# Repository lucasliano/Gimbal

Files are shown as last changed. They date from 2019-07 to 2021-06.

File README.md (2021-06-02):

<!-- Badged -->





<!-- PROJECT LOGO -->
<br />
<p align="center">
  <a href="https://github.com/lucasliano/Gimbal">
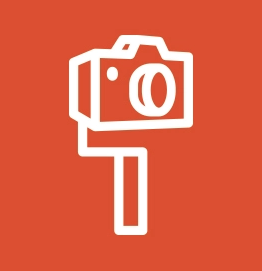
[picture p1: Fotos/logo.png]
    
  </a>

  <h3 align="center">3-Axis Gimbal</h3>

  <p align="center">
    Proyecto integrador de la materia Informática II, correspondiente a la carrera en Ing. Electrónica de la UTN.BA.
    En este proyecto se desarrolló un estabilizador de cámara GoPro de tres ejes.
    <br />
    <a href="https://github.com/lucasliano/Gimbal/blob/master/EntregaFinal/Gimbal%20Informe.pdf"><strong>Explore the docs »</strong></a>
    <br />
    <br />
    <a href="https://github.com/lucasliano/Gimbal/blob/master/Fotos">View Demo</a>
    ·
    <a href="https://github.com/lucasliano/Gimbal/issues">Report Bug</a>
    ·
    <a href="https://github.com/lucasliano/Gimbal/issues">Request Feature</a>
  </p>
</p>

<!-- ABOUT THE PROJECT -->
## About The Project




La idea fuerza del proyecto surgió gracias a las nuevas tecnologías utilizadas para la
transmisión de espectáculos en grandes espacios abiertos, tales como recitales o encuentros
deportivos en grandes estadios. El método utilizado inicialmente se basó en la utilización de cables
tensados y rieles en los cuales mediante un soporte, los elementos de filmación serían comandados
remotamente. Sin embargo, lejos de ser una solución, formuló un problema aún mayor; a una
determinada altura, los factores climáticos suponen un factor crítico a tener en cuenta que modifica la
precisión con la cual se puede manipular la herramienta de filmación.
Este inconveniente fue lo que motivó nuevos avances en materia de transmisiones. Referido
al problema inicial se propuso soportes acoplados en los extremos de las cámaras para poder
solventar el problema del viento y condiciones climáticas adversas.
A su vez, esta corriente tecnológica impulsó avances en la transmisión de deportes extremos
e individuales, para poder capturar experiencias que hasta el momento no podían ser alcanzadas. A
pesar de que no se trataba de deportes en los cuales la altura fuese un factor primordial, la velocidad,
los cambios bruscos de movimientos y repentinos presentaban el mismo problema descrito para
eventos masivos. La solución, sin embargo, esta vez fue diferente. Mediante la conjunción de
elementos que se detallarán a lo largo del documento, tanto en software y hardware, se logró el
elemento que nuestro proyecto intentará replicar, un estabilizador de cámara de tres ejes mediante
motores y algoritmos de control. Utilizaremos las cámaras para los cuales fueron diseñados
específicamente este elemento en primer lugar, las cuales pertenecen a la empresa goPro. En la
actualidad es posible utilizarlas en diferentes cámaras siempre y cuando se tenga en consideración el
peso y el tamaño de la cámara.

### Images

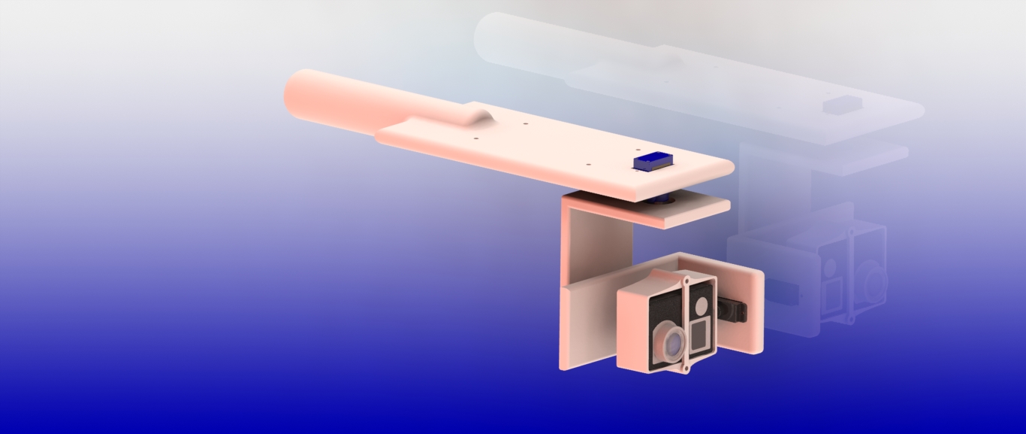
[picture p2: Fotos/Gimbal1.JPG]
gimbal


### Authors

* Coiro, Mateo
* Golob, Lautaro
* [Liaño, Lucas](https://github.com/lucasliano)
* [Lovallo, Alejo](https://github.com/AlejoLovallo)
* Repetto, Facundo

<!-- CONTRIBUTING -->
## Contributing

Contributions are what make the open source community such an amazing place to be learn, inspire, and create. Any contributions you make are **greatly appreciated**.

1. Fork the Project
2. Create your Feature Branch (`git checkout -b feature/AmazingFeature`)
3. Commit your Changes (`git commit -m 'Add some AmazingFeature'`)
4. Push to the Branch (`git push origin feature/AmazingFeature`)
5. Open a Pull Request

<!-- LICENSE -->
## License

Distributed under the MIT License. See `LICENSE` for more information.

<!-- CONTACT -->
## Contact

Lucas Liaño - lliano@frba.utn.edu.ar

Project Link: [https://github.com/lucasliano/Gimbal](https://github.com/lucasliano/Gimbal)

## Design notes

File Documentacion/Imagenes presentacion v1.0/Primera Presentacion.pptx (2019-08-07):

## Organización del TPO

- Diseñar:
  - Modelo 3D
  - Modelo matemático y físico
  - Modelo máquinas de estado (como funciona y lógica de abstracción)
  - Capa de aplicación
  - Capa de enlace
  - Capa física
  - Interfaz gráfica

## ¿Qué es un Gimbal?

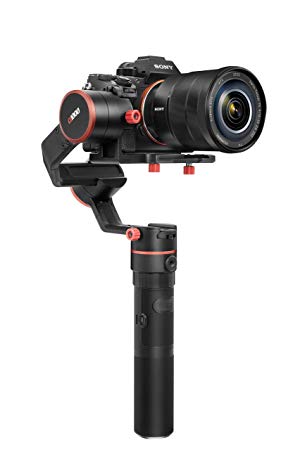
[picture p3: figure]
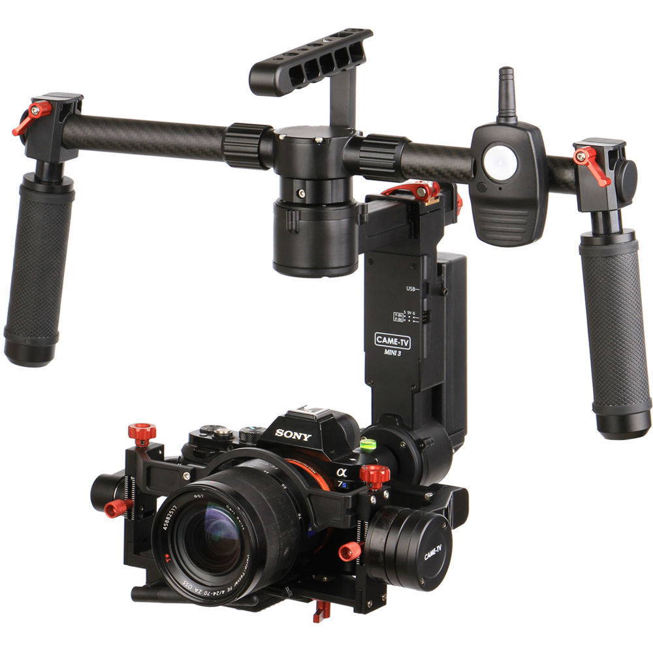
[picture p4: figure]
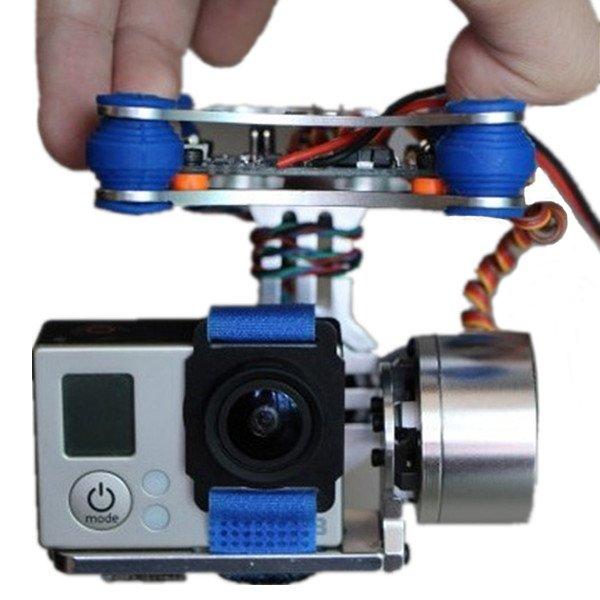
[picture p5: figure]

## Modelo 3D

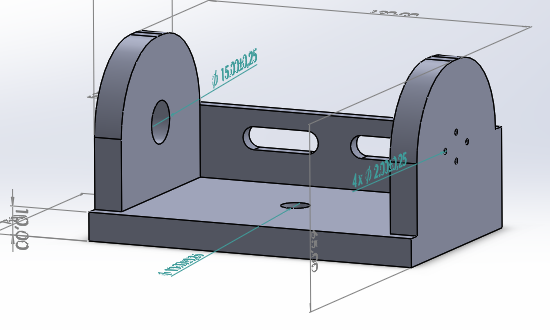
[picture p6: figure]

## Modelo 3D

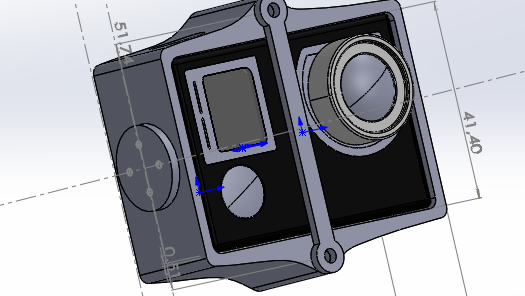
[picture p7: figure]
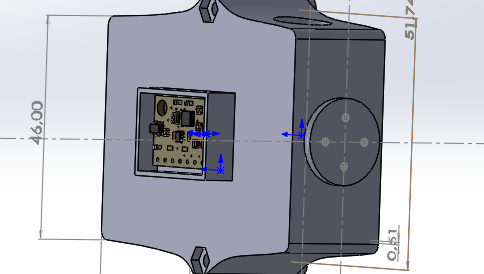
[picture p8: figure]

## Modelo Matemático y Físico

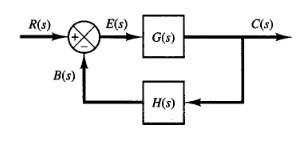
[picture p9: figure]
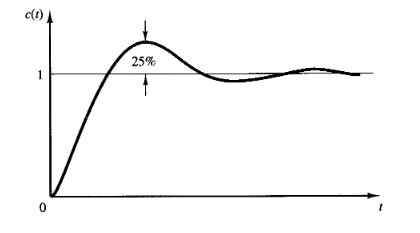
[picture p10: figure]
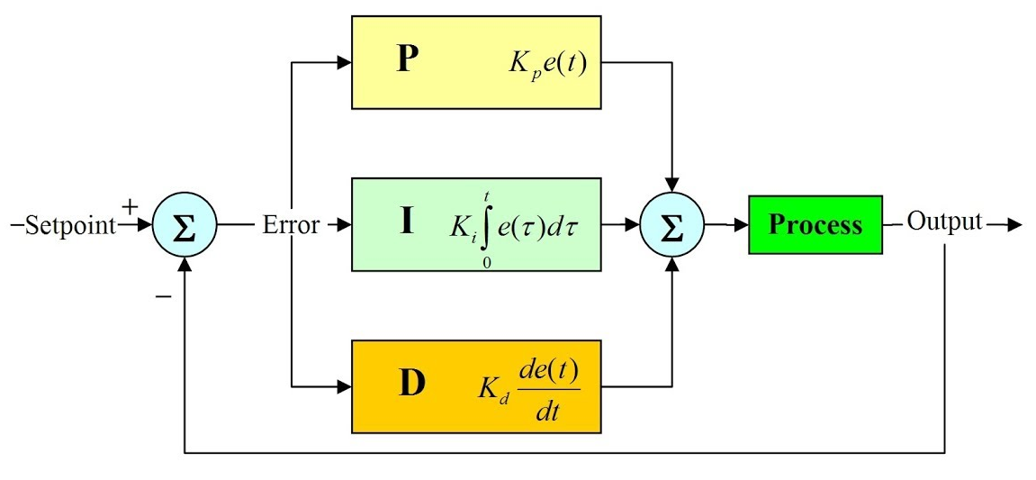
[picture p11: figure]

## Lógica de abstracción

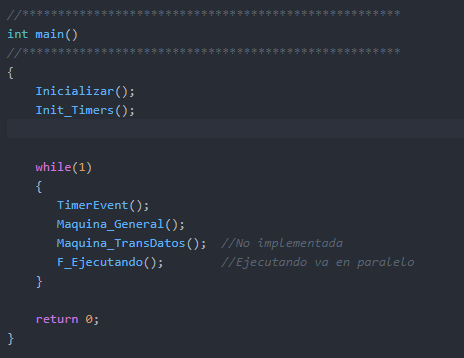
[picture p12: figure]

## Lógica de abstracción

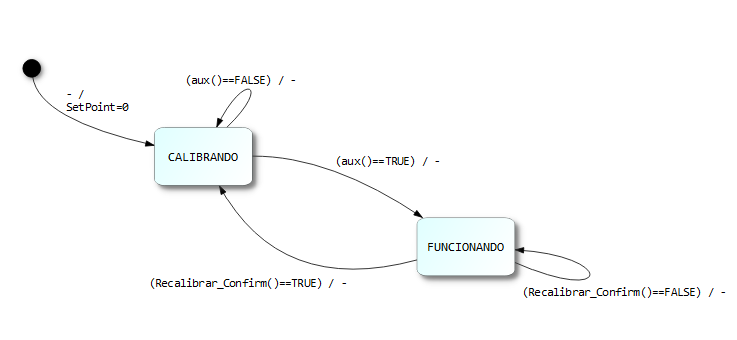
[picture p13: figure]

Maquina_General

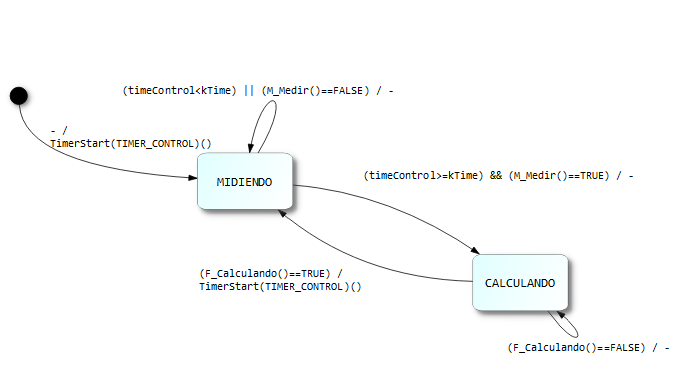
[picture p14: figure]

## Lógica de abstracción

Maquina_Control

## Capa de aplicación

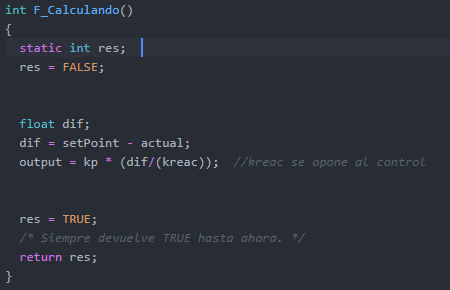
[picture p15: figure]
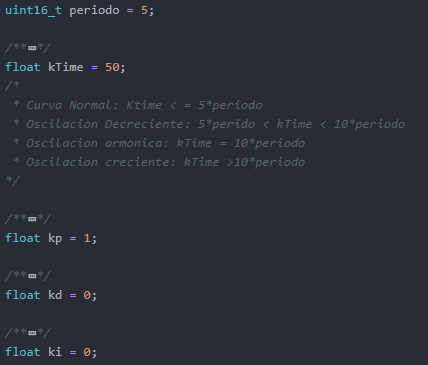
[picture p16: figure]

## Capa de “primitivas”

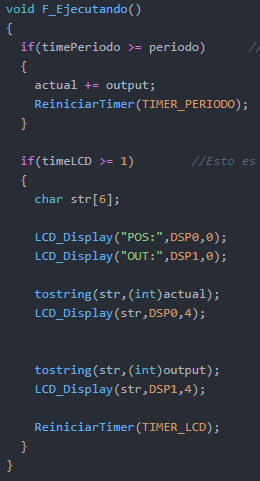
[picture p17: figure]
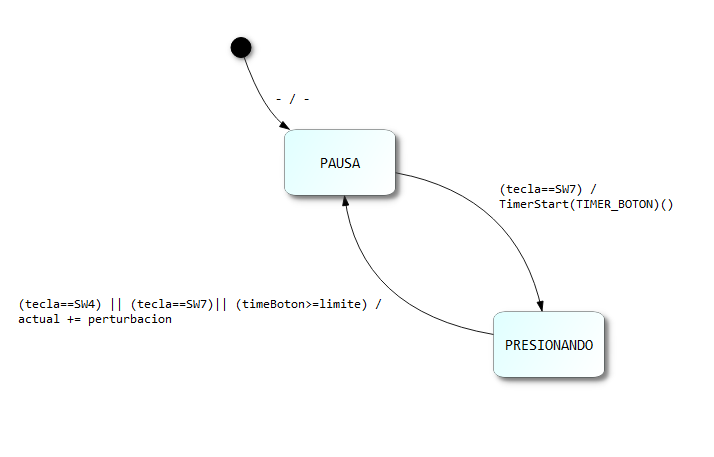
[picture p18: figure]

## Interfaz gráfica

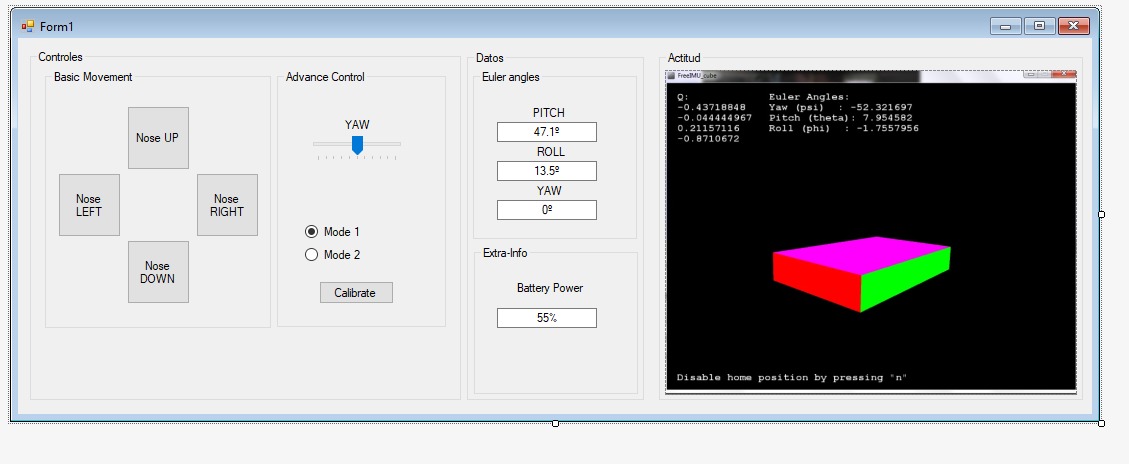
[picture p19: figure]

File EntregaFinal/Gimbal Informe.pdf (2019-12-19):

Universidad Tecnológica Nacional | Facultad Regional Buenos Aires
Departamento de Electrónica | Informática II - Plan 95A

# Trabajo Práctico Obligatorio: Informe

Materia: Informática II - Ing. Electrónica - U.T.N-F.R.B.A.

Docente titular: Ing. Nahuel Gonzalez

Ayudante de primera: Ing. Lisandro Sugezky

Ayudantes de segunda: Nicolás Campos

Federico Bua

Jefe de cátedra: Ing. Marcelo Giura

Integrantes: | Coiro, Mateo

Golob, Lautaro

Liaño, Lucas

Lovallo, Alejo

Repetto, Facundo

Trabajo Práctico Obligatorio | 1

# Estabilizador de cámara Gimbal

El propósito de este documento es resumir de manera informativa y práctica los aspectos técnicos del proyecto integrador.

- Estabilizador de cámara Gimbal
- Objetivo
- Descripción
- Marco Teórico
- Actuadores:
- Control:
■ Funcionamiento:
- Filtros:
- Recursos Complementarios
- Impresión 3D
- Módulos externos
- Placa complementaria
- Materiales utilizados para las placas
- Problemas y Soluciones
- Máquinas de estados:
- Interfaz gráfica:
- I2C:
- Traspaso del código a C++:
- Sistema de Control:
- Filtros:

Conclusiones

## Objetivo

Realizar un proyecto integrador que capitalice los conocimientos aprendidos durante la materia de Ingeniería Electrónica de segundo año, Informática II.
Los integrantes del equipo de trabajo hemos decidido realizar un estabilizador de cámara de tres ejes, más conocido como Gimbal en la industria. Será desarrollado específicamente para una cámara GoPro Hero 4.

### Descripción

La idea fuerza del proyecto surgió gracias a las nuevas tecnologías utilizadas para la transmisión de espectáculos en grandes espacios abiertos, tales como recitales o encuentros deportivos en grandes estadios. El método utilizado inicialmente se basó en la utilización de cables tensados y rieles en los cuales mediante un soporte, los elementos de filmación serían comandados remotamente. Sin embargo, lejos de ser una solución, formuló un problema aún mayor; a una determinada altura, los factores climáticos suponen un factor crítico a tener en cuenta que modifica la precisión con la cual se puede manipular la herramienta de filmación.
Este inconveniente fue lo que motivó nuevos avances en materia de transmisiones. Referido al problema inicial se propuso soportes acoplados en los extremos de las cámaras para poder solventar el problema del viento y condiciones climáticas adversas.
A su vez, esta corriente tecnológica impulsó avances en la transmisión de deportes extremos e individuales, para poder capturar experiencias que hasta el momento no podían ser alcanzadas. A pesar de que no se trataba de deportes en los cuales la altura fuese un factor primordial, la velocidad, los cambios bruscos de movimientos y repentinos presentaban el mismo problema descrito para eventos masivos. La solución, sin embargo, esta vez fue diferente. Mediante la conjunción de elementos que se detallarán a lo largo del documento, tanto en software y hardware, se logró el elemento que nuestro proyecto intentará replicar, un estabilizador de cámara de tres ejes mediante motores y algoritmos de control. Utilizaremos las cámaras para los cuales fueron diseñados específicamente este elemento en primer lugar, las cuales pertenecen a la empresa goPro. En la actualidad es posible utilizarlas en diferentes cámaras siempre y cuando se tenga en consideración el peso y el tamaño de la cámara.

### Marco Teórico

Centraremos nuestro análisis en tres ejes fundamentales para la comprensión de los fundamentos y complejidades del proyecto: Actuadores, Control-Filtros:

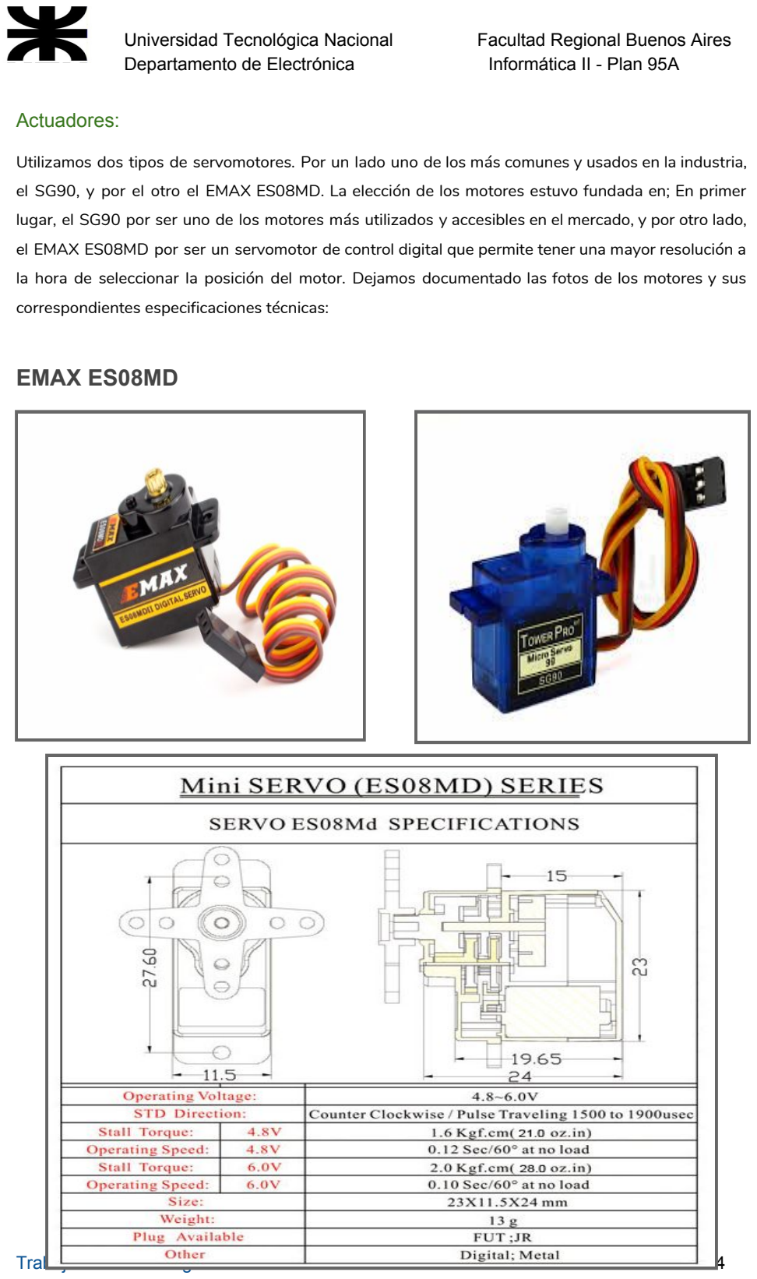
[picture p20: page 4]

Actuadores:

Utilizamos dos tipos de servomotores. Por un lado uno de los más comunes y usados en la industria, el SG90, y por el otro el EMAX ES08MD. La elección de los motores estuvo fundada en; En primer lugar, el SG90 por ser uno de los motores más utilizados y accesibles en el mercado, y por otro lado, el EMAX ES08MD por ser un servomotor de control digital que permite tener una mayor resolución a la hora de seleccionar la posición del motor. Dejamos documentado las fotos de los motores y sus correspondientes especificaciones técnicas:

### EMAX ES08MD

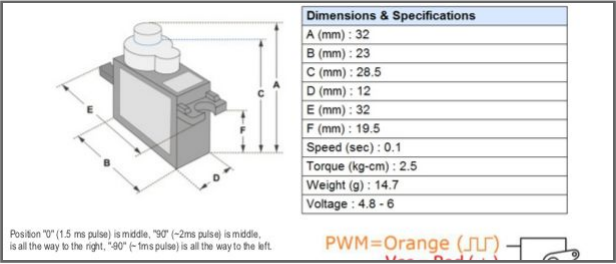
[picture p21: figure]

Control:

Se utilizó un mecanismo de control ampliamente conocido y utilizado en sistemas de control industrial por sus siglas: P.I.D (Controlador Proporcional, Integral y Derivativo). El mismo se basa de un sistema de realimentación, el cual calcula la desviación o error entre un valor medio y un valor deseado. El controlador puede proveer una acción de control adaptada a los requerimientos del proceso en específico. La respuesta del controlador puede describirse en términos de respuesta del control ante un error, el grado el cual el controlador sobrepasa el punto de ajuste, y el grado
de | oscilación | del sistema. Nótese que el uso del PID para control no garantiza un control óptimo
del sistema o la estabilidad del mismo.

Funcionamiento:

Para el correcto funcionamiento se necesita al menos:

- Sensor
- Controlador
- Actuador

A su vez, los tres componentes de un controlador PID son:

- Parte Proporcional --- constante proporcional.
- Acción Integral -------- tiempo Integral.
- Acción Derivativa ---- tiempo derivativo.

El sensor proporciona una señal analógica o digital al controlador, la cual representa el punto actual en el que se encuentra el proceso o sistema.
El controlador recibe una señal externa que representa el valor que se desea alcanzar, en nuestro caso el setPoint, el cual es de la misma naturaleza y tiene el mismo rango de valores que la señal que proporciona el sensor.

El controlador resta la señal de punto actual a la señal de punto de consigna, obteniendo así la señal de error, que determina en cada instante la diferencia que hay entre el valor deseado (consigna) y el valor medido. La señal de error es utilizada por cada uno de los tres componentes del controlador PID. Las tres
señales sumadas, componen la señal de
salida que el controlador va a utilizar para
gobernar al actuador. La señal resultante de la suma de estas tres se llama variable manipulada y no se aplica directamente sobre el actuador, sino que debe ser transformada para ser compatible con el
actuador utilizado.

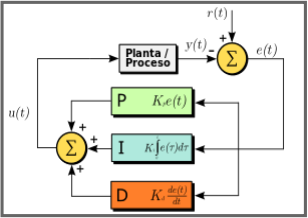
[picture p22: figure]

Se pretenderá lograr que el bucle de control corrija eficazmente, y, en el mínimo tiempo posible los efectos de las perturbaciones.

### Filtros:

Debido a la implementación de la I.M.U(Inertial measurement unit), es necesario aplicar filtros para la generación de ángulos de euler. En este caso en particular, utilizamos un filtro complementario que fusiona el ángulo generado a partir de la integración de la velocidad angular en un período AT junto con el ángulo generado a partir de cálculos trigonométricos sobre el vector gravedad, medido desde el acelerómetro. Por otro lado, aplicamos un filtro de media móvil exponencial aplicado como pasa-bajo. Esto se debe a que los datos tomados de la IMU tienen fluctuaciones de alta frecuencia.

### Proceso (https://es.wikipedia.org/wiki/N%C3%BAmeros_complejos)

El proceso para la organización y realización del proyecto fue diagramado por el cuerpo docente a cargo de la materia y posteriormente nuestro equipo lo modificó de acuerdo a las necesidades de nuestro proyecto en cuestión:

1. Presentación de la idea fuerza.
2. Establecimiento de limitaciones y alcance del proyecto coordinadas con el cuerpo docente:
- Desarrollo completo del modelo mecánico, tanto diseño como simulación e impresión del chasis del gimbal.

- Desarrollo del firmware que contará con funciones que posibiliten la rotación del soporte en torno a sus propios ejes y un modo de uso que permitirá controlar el sistema para mantener constante la actitud del soporte central de uno de los tres ejes.
- Desarrollo de una interfaz gráfica que pueda controlar y visualizar la actitud del dispositivo.
3. Lógica del proyecto mediante máquinas de estado.

Inicialmente se diagramó una lógica que contemplaba tres máquinas de estados

- Máquina general
- Máquina de control
- Máquina de transmisión de datos

Máquina General: La máquina general se encarga de las tareas principales que debe cumplir el sistema. La misma cuenta, a esta altura del proyecto, con dos estados FUNCIONANDO y CALIBRANDO. La máquina va a iniciar en el estado CALIBRANDO y va a ejecutar las rutinas pertinentes a la calibración. Una vez haya logrado calibrarse, función que actualmente no contempla fallos, genera una transición hacia FUNCIONANDO.

En el estado funcionando, el programa va a ejecutar la máquina de control. Luego va a generar una transición hacia calibrando si se cumplen los requisitos de Recalibrar_confirm() = aux. Esto va a suceder ya sea porque se solicita una recalibración vía comunicación Serie o porque se ha congelado el micro.

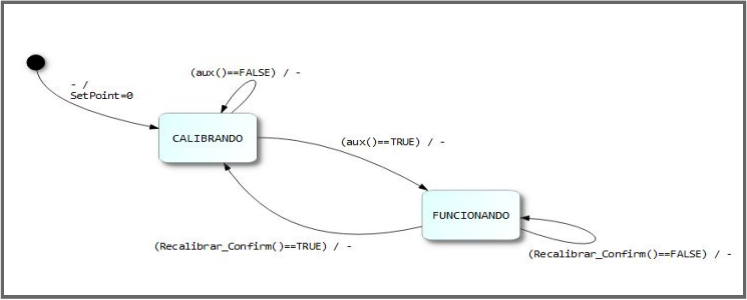
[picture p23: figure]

Máquina Control: La máquina de control se encarga de alternar entre mediciones y cálculo de datos. La transición es temporizada y depende de una constante de control kTime. Dentro del estado MIDIENDO se realizan cuantas mediciones sean posibles de datos y se procesan obteniendo ángulos de Euler. Cuando se genera la transición al estado CALCULANDO, se ejecutan los cálculos del sistema de control, obteniendo como resultado una salida “output” que debe incrementarse en la variable “actual” (correspondiente a la función F_Ejecutando().

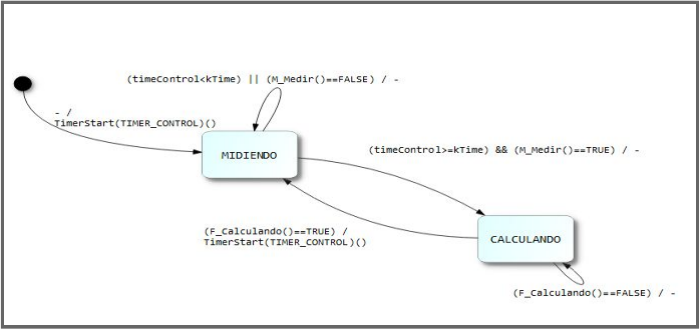
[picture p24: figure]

Máquina transferencia de datos: Esta máquina cuenta con 3 estados que se ocupan del correcto desempeño de la recepción de mensajes vía puerto serie. Estos tres estados son ESPERANDO_INICIO, ESPERANDO_TIPOS y RECIBIENDO_DATOS.

El estado inicial es ESPERANDO_INICIO. Allí se espera la llegada de un carácter ‘#’. Cuando eso ocurre, empieza la recepción de la trama y estado pasa a ser ESPERANDO_TIPO. En este nuevo estado se espera la llegada de 3 caracteres que definen el tipo de mensaje. Si la cantidad de caracteres que llegan hasta la llegada de un ‘@‘ es distinta a 3 unidades, entonces se descarta la trama y se vuelve al estado ESPERANDO_INICIO. Cuando la cantidad de caracteres recibidos supere 3 unidades sin la llegada de un ‘@‘, entonces el estado se modifica a RECIBIENDO_DATOS. Mientras la máquina se encuentre dentro de RECIBIENDO_DATOS, se esperará la llegada de un nuevo carácter y a continuación un ‘@‘. Si no se cumplen dichas condiciones, se descarta la trama. Si se cumplieran las condiciones, se llama a la la función AnalizarTrama(), quien verifica el tipo de dato y ejecuta acciones conforme al tipo de mensaje.

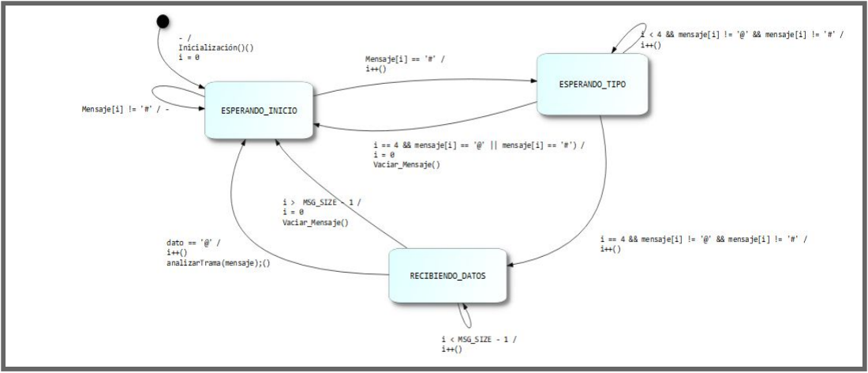
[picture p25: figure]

4. Modelizado del funcionamiento mediante la utilización de la librería de la cátedra conjuntamente con los periféricos incluidos en la placa.
5. Presentación de la interfaz gráfica del proyecto
6. Presentación de avances preliminares.
7. Presentación Final.

Se estableció una forma de trabajo en un principio conjunta y que posteriormente se dividiría por áreas para cumplir con los tiempos solicitados por la cátedra. A su vez, desde un primer momento incorporamos a nuestro modo de trabajo dos herramientas necesarias y sumamente útiles para cualquier tipo de proyecto;

- Documentación mediante Doxygen.
- Software de gestión de versiones de código, en nuestro caso mediante GitHub.

### Recursos Complementarios

### Impresión 3D

Era desde un primer momento, un aspecto a tener en cuenta desde que tomamos la decisión de avanzar en el proyecto. El estabilizador que se produce a nivel industrial utiliza materiales que eran perfectamente replicables a través de la impresión 3D. Por lo tanto, diseñamos cuatro piezas para que la cámara que utilizaremos, una GoPro Hero4 pueda ser utilizada en el proyecto.
Utilizamos el programa SolidWorks para el diseño en 3D de las piezas y para poder realizar el renderizado para que la impresora 3D comprenda el modelo realizado el software Cura.

Descripción de las piezas realizadas:

- Caja a medida para que colocar la cámara: el propósito de esta pieza es darle un alojamiento a la cámara.
- Tabique para sostener la cámara: por cuestiones de diseño, la realización de una tapa para que la cámara no se caiga era difícil de alcanzar por lo que se implementó un tabique en el el frente de la caja, a la cual se agujereó en el medio de la misma tanto en la

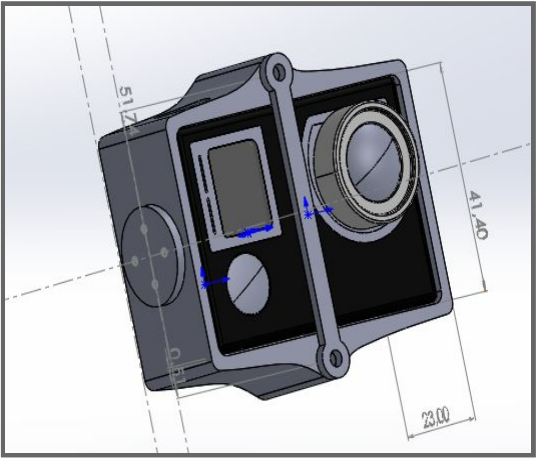
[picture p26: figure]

parte superior como inferior de la misma.

- Dos soportes los cuales forman ángulos perpendiculares entre sí y permiten que la sujeción de los servomotores para luego generar rotaciones.
- Mango para la manipulación del dispositivo y a su vez cumple la función de sujetar la placa a la base del mango.



### Módulos externos

Para realizar mediciones correspondientes recurrimos a uno de las unidades de medición inercial más conocidas como lo es el MPU-9250. El mismo es un integrado que cuenta con un giroscopio, un acelerómetro y un magnetómetro. También tiene interfáz para comunicación mediante tanto I2C com SPI.

Por otro lado, para generar una comunicación inalámbrica con Qt optamos por utilizar el módulo HC-06. Este es un módulo muy utilizado en el mundo Arduino capaz de comunicarse mediante Bluetooth con distintos dispositivos. Para conectarnos con él, solo tendremos que escribir en una UART, una vez hayamos configurado el módulo.

### Placa complementaria

Los motivos de la realización de una placa complementaria se encuentran en la necesidad de poder alimentar los servomotores de una manera práctica que permita el movimiento de los mismos, y la única manera de realizarlo era con el diseño y confección de una placa que pudiese estar montada sobre el gimbal, y como la placa provista por la cátedra no cumplía con nuestros requisitos decidimos realizar una nueva.


Materiales utilizados para las placas

- Dos Borneras de 2
- Un Diodo 1N5819
- Un Diodo 1N4007
- Dos Capacitores 0,1uF
- Dos Capacitores 0.22 uF

- Dos Capacitores 10mF x 16V
- Un Regulador LM7805
- Un Regulador LM1117T3.3
- Dos Resistencias 4,7Kohm
- Varias Tiras de pines hembra

### Problemas y Soluciones

### Máquinas de estados:

Al comienzo del año nuestro primordial objetivo fue consolidar cual iba a ser la lógica general del funcionamiento del dispositivo en cuestión. Para ello utilizamos como funciones de referencia, toda la biblioteca que proporciona la cátedra.
El principal problema que hubo con las máquinas de estado fue que en un primer momento se plantearon desde un nivel de aplicación bastante abstraído del funcionamiento de los drivers, sin considerar el comportamiento de las interrupciones. También tenemos en cuenta que para el comienzo del año no contábamos con los conocimientos acerca de las interrupciones.
La solución en este caso fue re-hacer parte del funcionamiento de las máquinas abstrayendo aún más la capa de aplicación, pero incluyendo más herramientas en la capa de primitivas.

### Interfaz gráfica:

Para el desarrollo de la interfaz gráfica se intentó desarrollar una aplicación que utilizara alguna librería gráfica como lo son Allegro o OpenGL. Nos encontramos con que estas librerías, en particular OpenGL, son bastante más complejas de lo que esperábamos. En ambos casos resultaba altamente dificultoso vincular las aplicaciones de Qt con las pantallas que generaban ambas herramientas. También se trató de agregar una aplicación externa, previamente realizada por uno de los integrantes, hecha en Java. Aquí el problema que encontramos era compatibilizar el método para acceder a la misma información, dado que no eran distintos procesos pero tampoco compartían las mismas variables globales. Qt no compatible con otros lenguajes ó entornos de trabajo.
En este caso, la solución que encontramos para representar gráficamente la actitud de la cámara fue la utilización de una librería propia de Qt (qcustomplot) para generar gráficos complejos en tiempo real. Aparte se agregó un feature para manipular las constantes de control desde la aplicación en la computadora.


I2C:

Referido al periférico I2C, podemos decir que fue una de nuestras mayores complicaciones, dado que nos costó entender que para poder solucionar los problemas que teníamos debíamos leer reiteradas veces el datasheet. Esto sumado a que para poder evaluar el comportamiento del periférico es necesario la utilización de instrumental como un osciloscopio, del cual no disponemos en nuestras casas, y también fue otro instrumento que debimos aprender a utilizar. Esta fue sin dudas, la etapa del proyecto más ardua y tediosa. Agradecemos el esfuerzo de los ayudantes para con nosotros y su paciencia y dedicación para poder sobrepasar esta etapa.

### Traspaso del código a C++:

Traspasar el firmware en MCU del lenguaje C al lenguaje C++ resultó ser más complicado de lo esperado. Para manipular la IMU, optamos con adquirir un código en c++ que contenía un objeto capaz de realizar muchas de las tareas necesarias. Si bien no terminamos utilizando la totalidad del objeto, dado que algunas de las rutinas contenían errores, de todas formas intentamos agregar este objeto en el firmware.
Para realizarlo, tuvimos que migrar el proyecto de C a C++. Esto implica que ahora es necesario que haya más de un compilador y un linker vinculados trabajando sobre el mismo código. Esto nos generó confusiones, dado que dependiendo cómo se declaran ciertos tipos de datos, defines o instrucciones pre-compilador, van a generar reacciones en algunas partes del código o no. Por tanto ciertos bugs que creíamos relacionados a la lógica del programa, terminaron estando vinculados con estos problemas de tener más de un compilador corriendo al mismo tiempo.

### Sistema de Control:

Diseñar e implementar un sistema de control no es nada trivial. A pesar de no tener conocimientos reales de control, intentamos implementar uno de los algoritmos más utilizados comercialmente como se mencionó anteriormente.
Nuestra ignorancia en esta área provocó que nos atrasemos demasiado en el desarrollo del proyecto. Resultó que nuestros actuadores (servomotores) resultan bastante difícil de modelar, o al menos así lo vemos nosotros, y generan interacciones no deseadas en el sistema.
Tuvimos para esta etapa la ayuda de uno de los grupos de investigación de la facultad, relacionado a drones, con lo cual han implementado varios sistemas de control distintos. Sin embargo, sólo fue una guía, completamente necesaria de todos modos, para poder realizarlo.

### Filtros:

Los filtros implementados fueron, en gran medida, diseñados por nosotros. Inicialmente, como se indicó en la sección de C++, se trató de utilizar un objeto diseñado por un profesional estadounidense. Este objeto utilizaba tanto las mediciones del acelerómetro, el giroscopio como del magnetómetro. Debido a que las mediciones obtenidas por el magnetómetro eran anormales, se buscó la forma de migrar el filtro. Por dicho motivo pasamos de utilizar el filtro Madgwic a utilizar un filtro complementario, junto con un filtro pasa-bajo, ambos diseñados por nosotros, o al menos en gran medida.
Los resultados obtenidos por los primeros intentos de filtros eran demasiado ruidosos (+/- 10 grados), por lo que no resultaban adecuados para nuestro dispositivo.
Luego de múltiples intentos, y una pequeña ayuda externa, logramos identificar dónde estaba el problema, en uno de los objetos al intentar realizar una pre-calibración. Por tomar como válido este cálculo externo, generamos datos erróneos los cuales generaban ruido en la señal de retroalimentación.
Una vez encontrado el problema, lo único que tuvimos que hacer fue re-hacer las funciones de calibración del objeto. Actualmente la señal resultante tiene un error de +/- 1 grado, lo cual tomamos como válido para nuestro fin.

### Conclusiones

A pesar de que el proyecto está orientado por la cátedra a que se evalúe solamente el software y no se contemple el hardware, el producto final al que se intentó llegar significó un desafío enorme para todo el equipo de trabajo. Tuvimos que lidiar con la inexperiencia de casi todos los integrantes en cuanto a hardware, diseño, armado y soldado de placas, protocolos de comunicación entre periféricos como lo fue I2C y sistemas de control. Con lo cual el tiempo empleado en tan sólo la comprensión de esos conocimientos fue muy grande comparado con el tiempo empleado en aplicarlos.

Sin embargo, al tratarse de una temática libre, la dificultad del proyecto fue alta desde un principio y a nuestro criterio, quizás no proyectamos los posibles inconvenientes y zonas de conflicto que podrían llegar a suceder mientras escalaba el proyecto. Fue desde un primer momento, una propuesta ambiciosa.

Si nos limitamos a evaluar de manera general si cumplimos con el objetivo inicial propuesto, podemos aseverar que se han alcanzado las condiciones mínimas del proyecto. Si lo detallamos, entonces la conclusión es que no estamos completamente satisfechos con los resultados. Es posible la realización de mejoras, tales como:

- Componentes, ya que los utilizados no son los más adecuados para el proyecto en cuestión.
- Filtros, ya que es la primera vez que realizamos este tipo de sistema.
- Control, por el mismo motivo detallado en filtros, consideramos que en esta área es dónde más mejoras podrían realizarse.

A pesar de todos los inconvenientes previamente mencionados a lo largo del documento, consideramos que la experiencia es en definitiva beneficiosa para el alumnado sobre todo en un ítem no mencionado, el trabajo en equipo. Destacamos el compromiso, organización y dedicación por parte de todos para con el proyecto y el entusiasmo y decisión con la que se llevó adelante todo el proceso desde el momento en que se decidió una idea y cuál era el camino a seguir.

Ciclo Lectivo 2019 | Curso Nº | R2003 | Grupo Nº | 3

## Integrantes

Apellido y nombres | Legajo | Califación individual | Fecha
Coiro, Mateo | 1672538 | | 16/12/2019
Golob, Lautaro | 1672587 | | 16/12/2019
Liaño, Lucas | 1674389 | | 16/12/2019
Lovallo, Alejo | 1673658 | | 16/12/2019
Repetto, Facundo | 1674705 | | 16/12/2019
Calificación Grupal: | Fecha: 16/12/2019
Profesor: | Ing. Nahuel Gonzalez
Auxiliar/es docente: | Ing. Lisandro Sugezky Sr. Nicolás Campos Sr. Federico Bua

### Observaciones primera entrega:

### Observaciones segunda entrega:

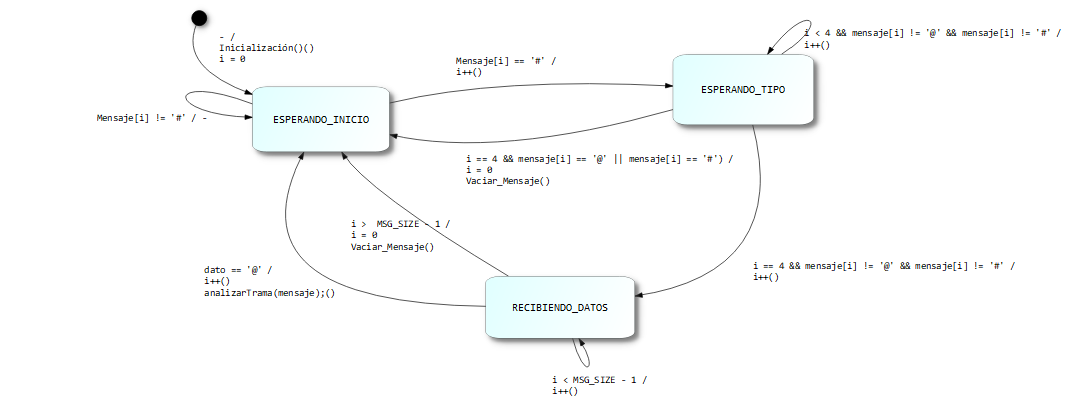
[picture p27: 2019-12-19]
Fotos/Maquina_TransDatos.png

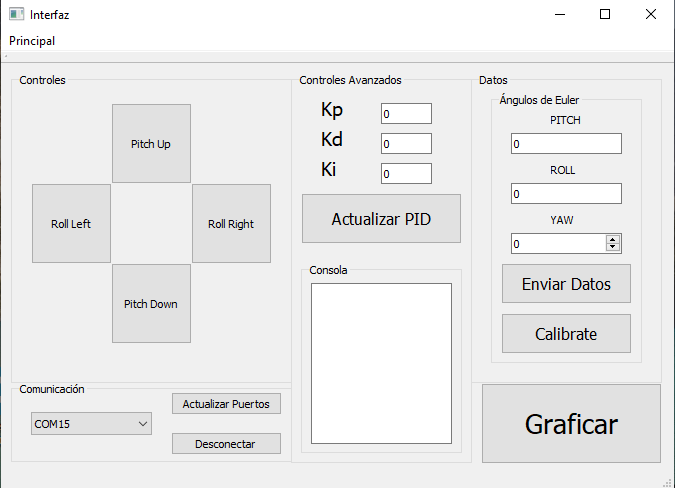
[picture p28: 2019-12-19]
Fotos/GUI-Activado.png

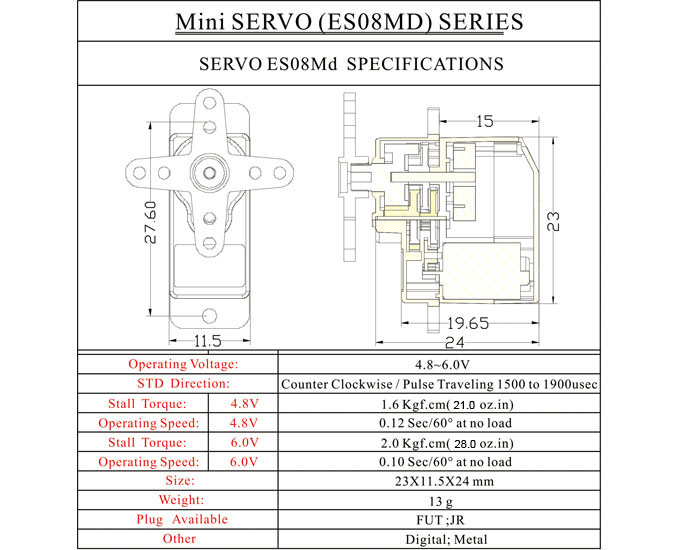
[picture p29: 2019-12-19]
EntregaFinal/FotosGimbal/EMX-SV-0276-DES-1.jpg

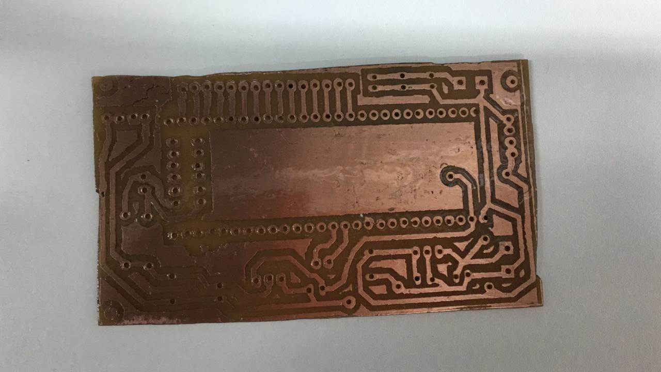
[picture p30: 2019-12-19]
EntregaFinal/FotosGimbal/PlacaComplementaria.jpg

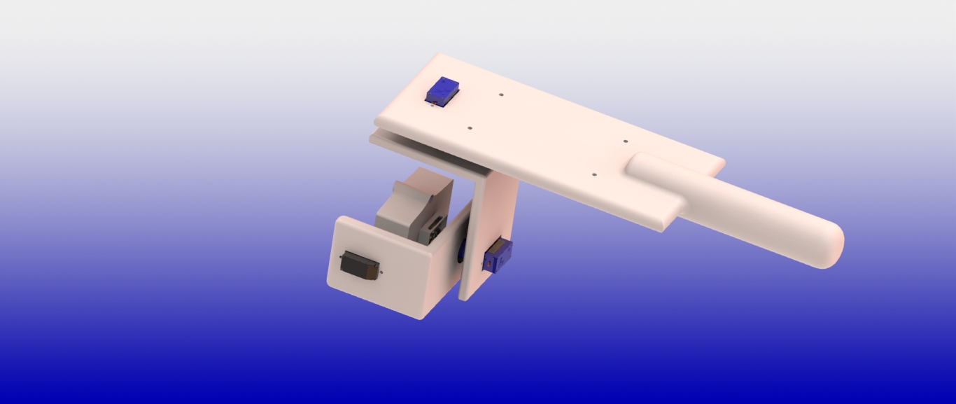
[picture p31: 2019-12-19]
Fotos/Gimbal3.JPG

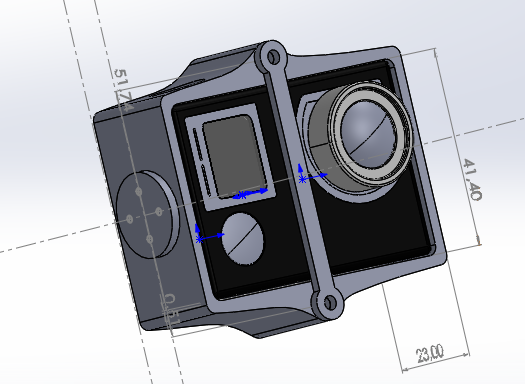
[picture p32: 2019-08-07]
EntregaFinal/FotosGimbal/Gimbal frente.png

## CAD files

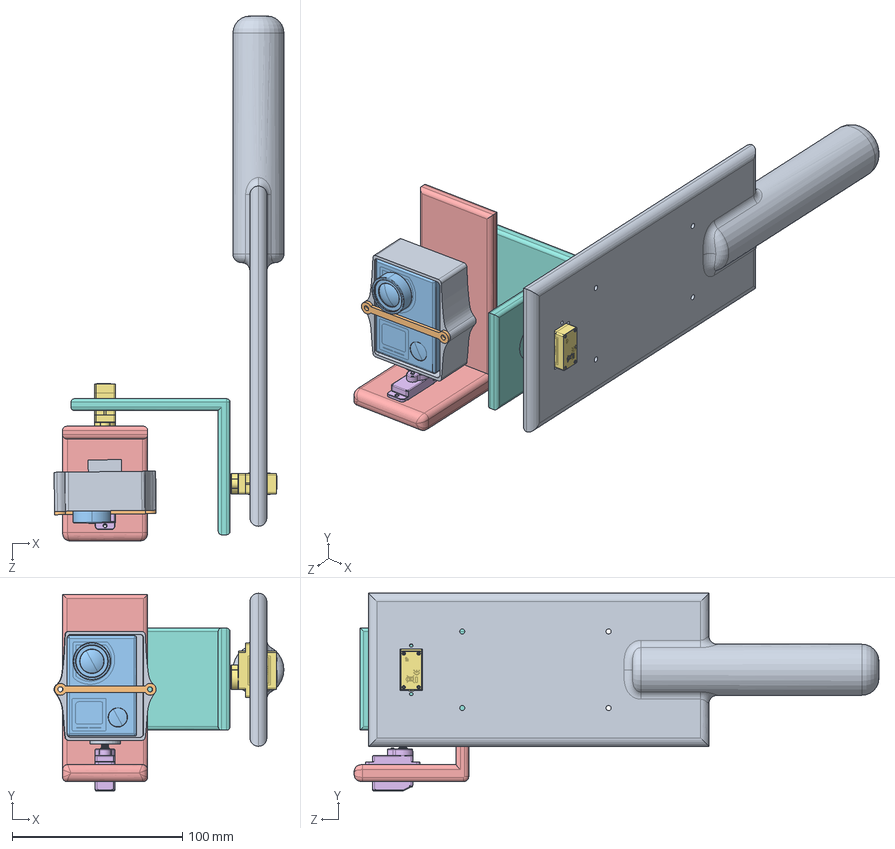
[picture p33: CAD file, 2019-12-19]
Piezas 3D/v3.0/Ensamblaje.SLDASM
135.2 x 116.2 x 308.6 mm
Pieza 1
Freno
Gopro Hero 4
GY-91
Pieza2
Emax ES08A
SG90 - Micro Servo 9g - Tower Pro.1 x 2
Pieza3
Pieza4

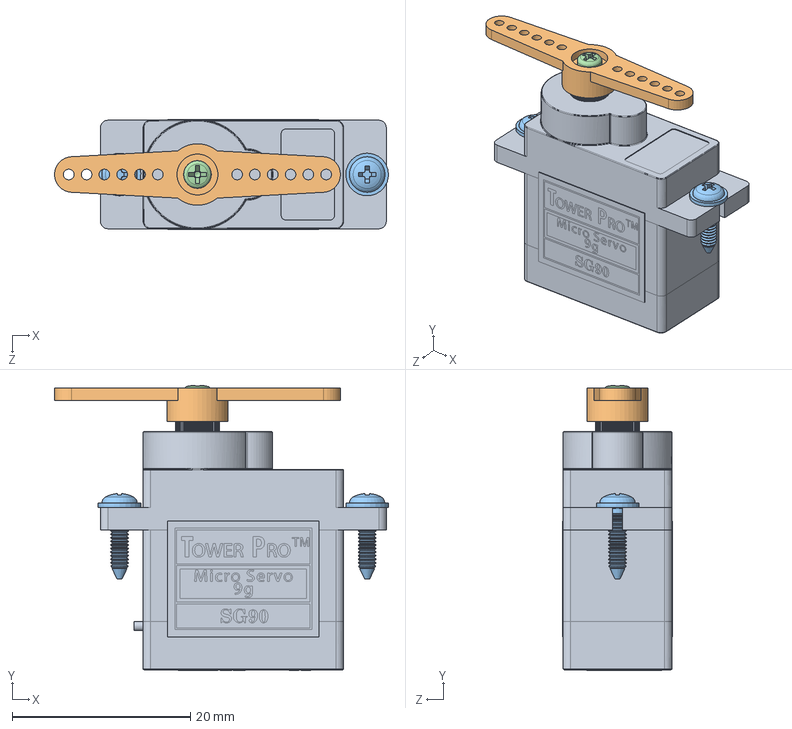
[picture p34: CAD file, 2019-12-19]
Piezas 3D/v3.0/Piezas externas/Servos/SG90/SG90 - Micro Servo 9g - Tower Pro.SLDASM
37.5 x 32.0 x 12.4 mm
SG90 - Micro Servo 9g - Tower Pro.1
SG90 - Micro Servo 9g - Tower Pro.3
SG90 - Micro Servo 9g - Tower Pro.5 x 2
SG90 - Micro Servo 9g - Tower Pro.6

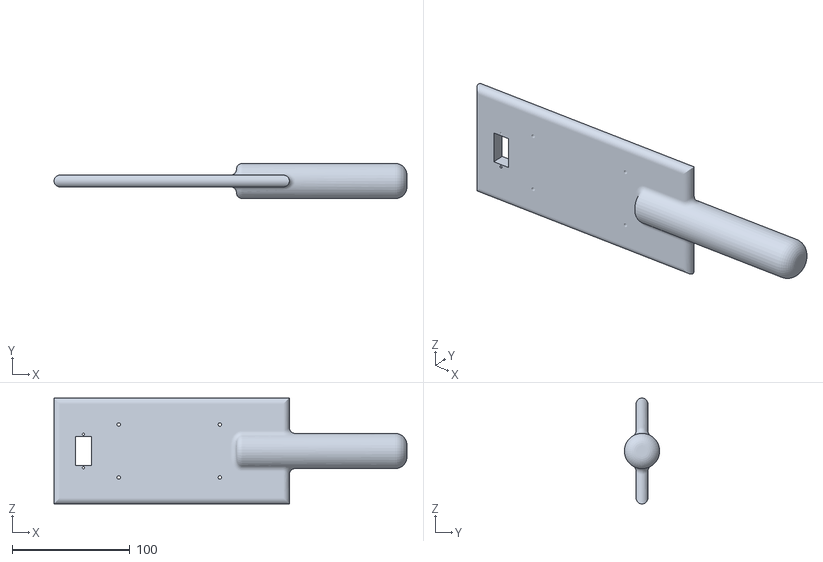
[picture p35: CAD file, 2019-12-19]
Piezas 3D/Pieza4.STL
300.0 x 30.0 x 90.0

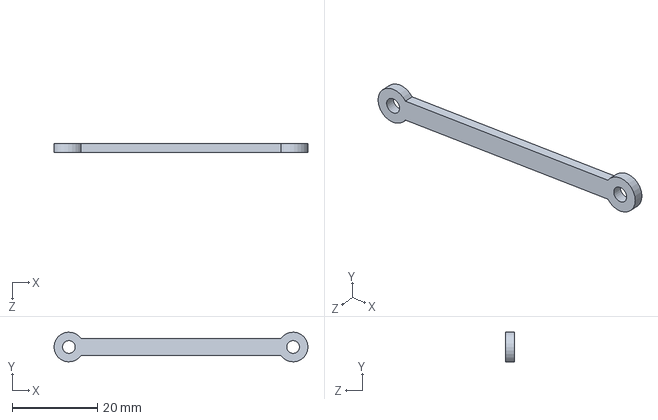
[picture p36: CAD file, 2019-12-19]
Piezas 3D/v3.0/Freno.SLDPRT
59.7 x 6.99 x 2.00 mm

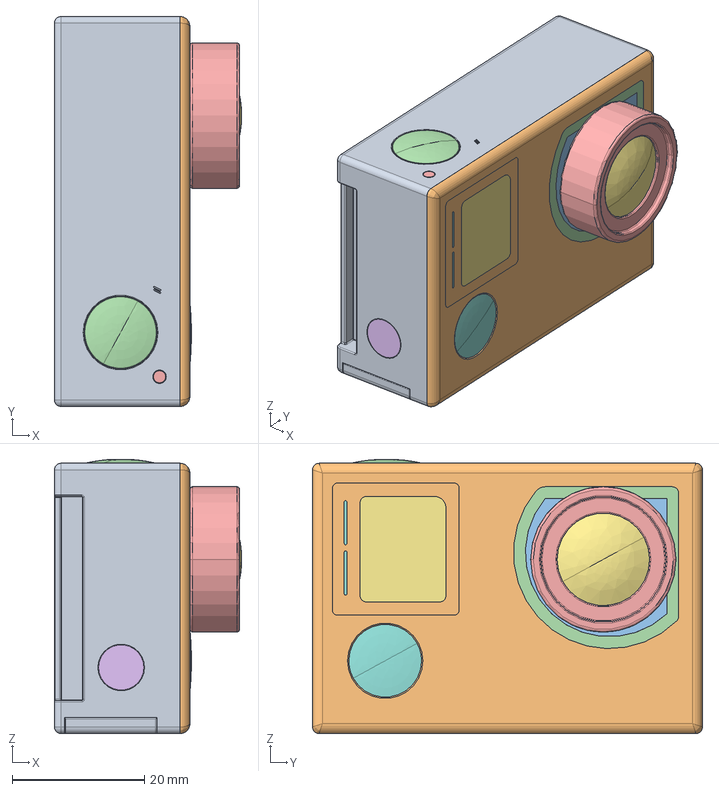
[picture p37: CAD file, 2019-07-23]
Piezas 3D/v3.0/Piezas externas/GoPro/Gopro Hero 4.stp
28.3 x 59.0 x 41.5 mm

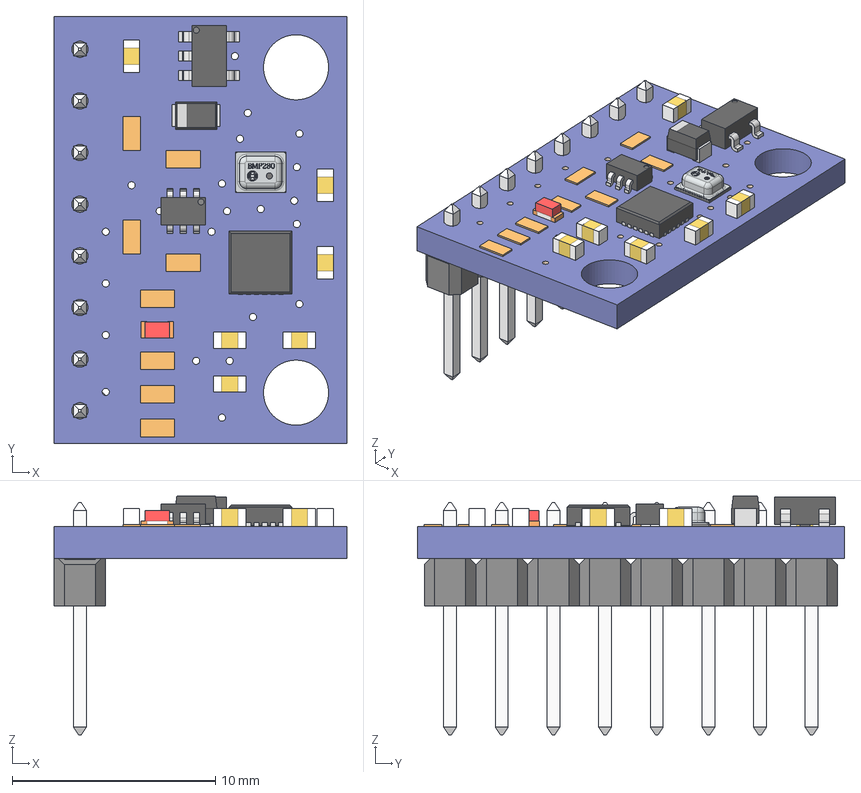
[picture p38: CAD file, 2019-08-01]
Piezas 3D/v3.0/Piezas externas/Gyro/GY-91.step
14.4 x 21.0 x 11.8 mm
Board
0.1µF x 6
BSS138PS(SOT-363)
Green
10µF
MIC550X-3v3
4.7kΩ x 8
2.54MM1X8
MPU9250
BMP280AU

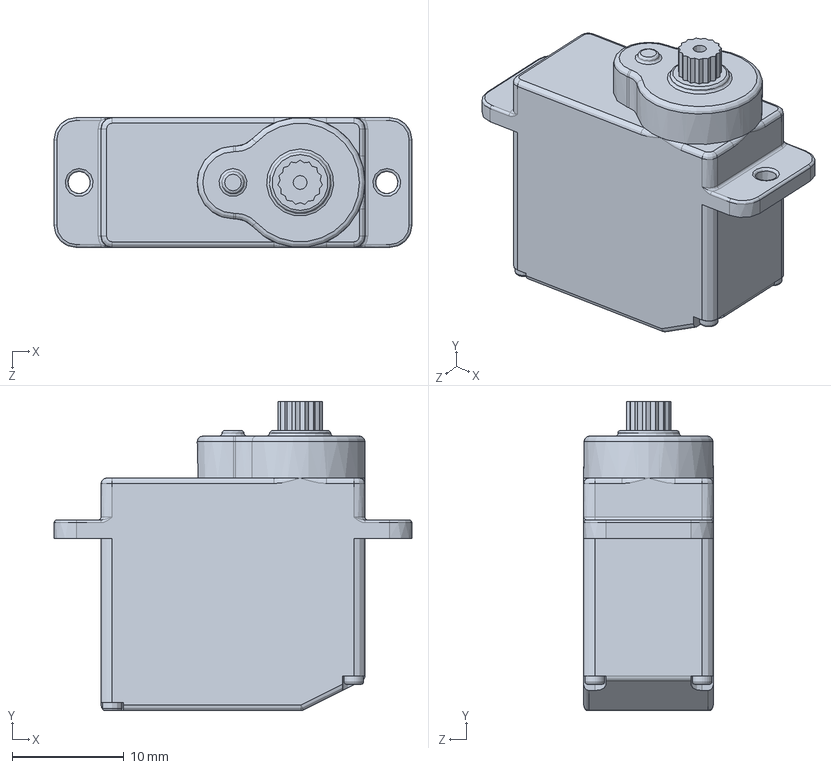
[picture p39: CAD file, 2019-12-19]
Piezas 3D/v3.0/Piezas externas/Servos/Emax - ES08A/Emax ES08A.SLDPRT
32.0 x 27.6 x 11.6 mm

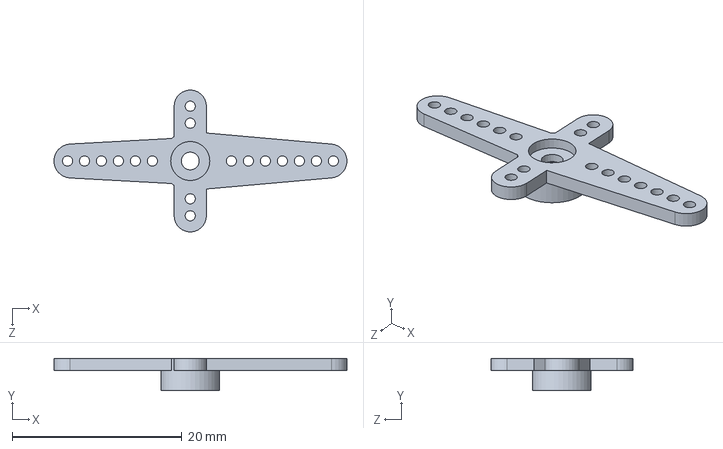
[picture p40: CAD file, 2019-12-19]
Piezas 3D/v3.0/Piezas externas/Servos/SG90/SG90 - Micro Servo 9g - Tower Pro.4.SLDPRT
34.5 x 3.80 x 16.7 mm

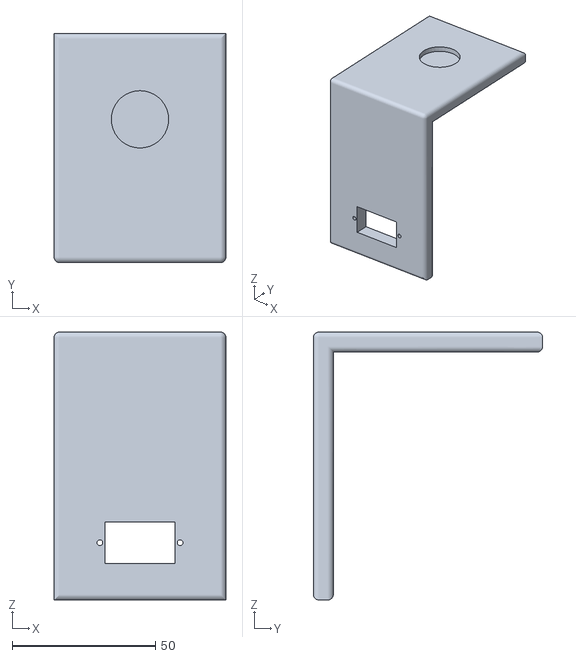
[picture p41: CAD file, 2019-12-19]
Piezas 3D/3era pieza.STL
60.0 x 80.0 x 93.5

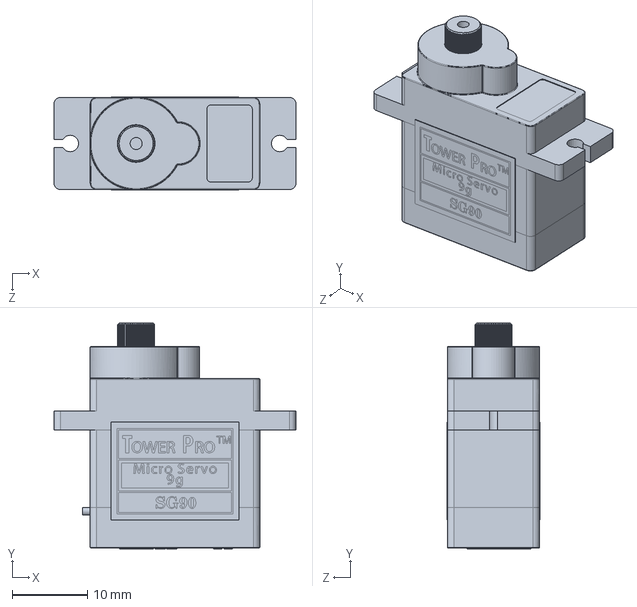
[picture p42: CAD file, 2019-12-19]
Piezas 3D/v3.0/Piezas externas/Servos/SG90/SG90 - Micro Servo 9g - Tower Pro.1.SLDPRT
32.1 x 30.0 x 12.4 mm

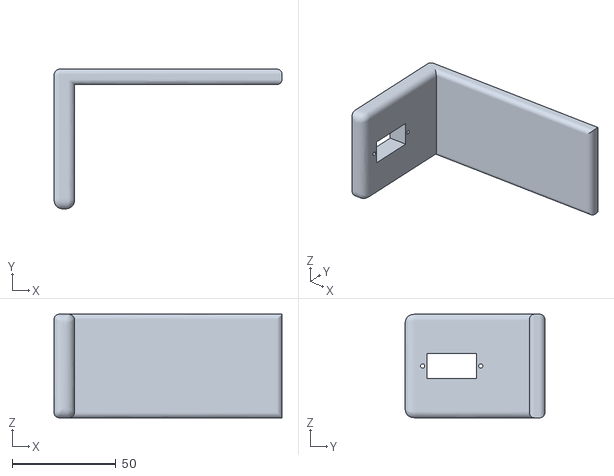
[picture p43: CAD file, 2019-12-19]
Piezas 3D/2da pieza.STL
110.0 x 67.5 x 50.0

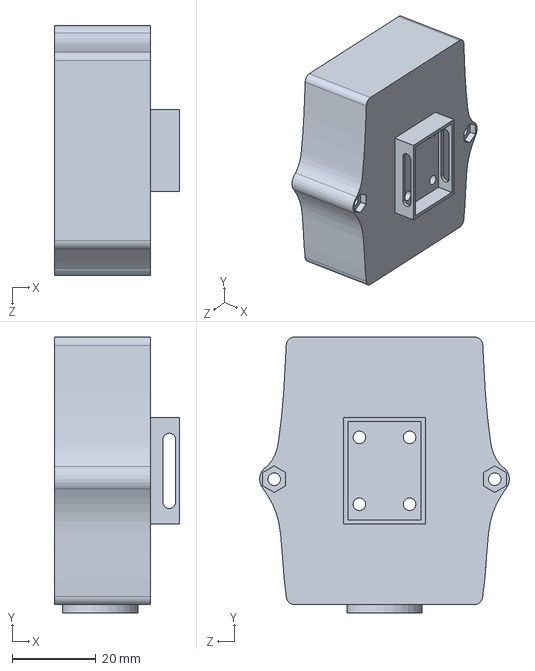
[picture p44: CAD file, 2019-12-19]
Piezas 3D/v3.0/Pieza 1.SLDPRT
30.0 x 66.0 x 59.7 mm

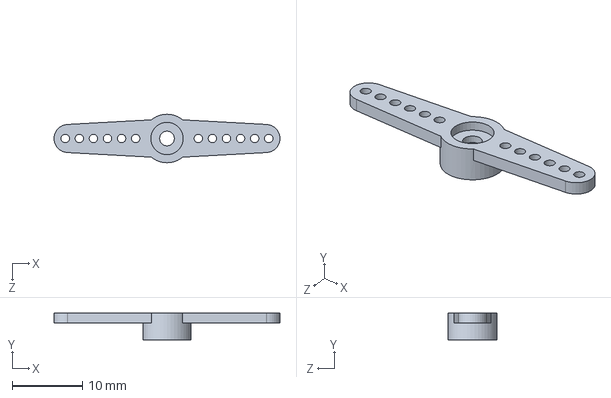
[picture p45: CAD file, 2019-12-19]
Piezas 3D/v3.0/Piezas externas/Servos/SG90/SG90 - Micro Servo 9g - Tower Pro.3.SLDPRT
32.1 x 3.80 x 6.90 mm

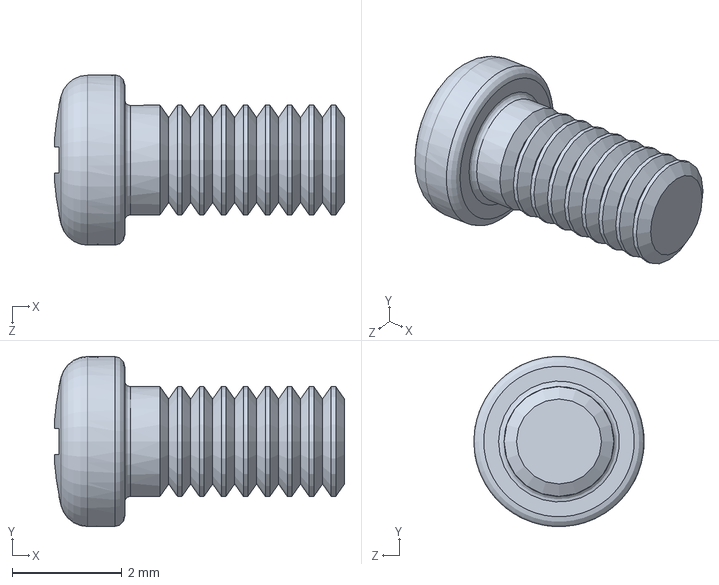
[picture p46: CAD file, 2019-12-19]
Piezas 3D/v3.0/Piezas externas/Servos/SG90/SG90 - Micro Servo 9g - Tower Pro.6.SLDPRT
5.28 x 3.10 x 3.10 mm

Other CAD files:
Piezas 3D/1era pieza.STL
Piezas 3D/v3.0/Pieza4.SLDPRT
Piezas 3D/Freno.STL
Piezas 3D/v3.0/Pieza2.SLDPRT
Piezas 3D/v3.0/Pieza3.SLDPRT
Piezas 3D/v3.0/Piezas externas/GoPro/Gopro Hero 4.SLDPRT
Piezas 3D/v3.0/Piezas externas/Gyro/GY-91.SLDPRT
Piezas 3D/v3.0/Piezas externas/Servos/SG90/SG90 - Micro Servo 9g - Tower Pro.2.SLDPRT
Piezas 3D/v3.0/Piezas externas/Servos/SG90/SG90 - Micro Servo 9g - Tower Pro.5.SLDPRT
Piezas 3D/v3.0/Piezas externas/Servos/SG90/SG90 - Micro Servo 9g - Tower Pro.x_t

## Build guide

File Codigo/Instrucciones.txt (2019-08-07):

Para poder bajar el proyecto hay que hacer lo siguiente:

1. Agarar el Proyecto.zip y importarlo desde el MCU en un Workspace LOCAL!!!!. Esto quiere decir, el workspace NO puede 
	estar en la carpeta de github.

2. Una vez cargado el proyecto en tu workspace local, como lo unico que va a variar del proyecto son las carpetas "src"
	y "inc", entonces arrastras esas carpetas desde el directorio de github (Es decir, el directorio de este archivo)
	hacia el workspace LOCAL de tu mcuxpress.

3. Te codeas la vida

4. Cuando quieras subir cambios, lo que vas a tener que hacer es copiar las carpetas del workspace local al directorio de
	github y clickeas "reemplazar". 

5. Abrir GitHub desktop y haces el push. 

Es simple. Es CLARO. :)

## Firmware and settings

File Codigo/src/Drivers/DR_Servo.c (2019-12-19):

/**
  \file DR_Servo.c
  \brief Se encuentran las rutinas asociada al funcionmamiento de los servomotores por GPIO.
  \author Grupo 8 - R2003
  \date 2019.07.23
  \version 1.2
*/
#include "all.h"



uint8_t flagServo[2] = {0,0};
uint16_t proximoDuty[2] = {1500,1500};
uint16_t  duty[2] = {1500,1500};


void ActualizarServosGPIO(void)
{
   for( int i = 0; i < 2; i++)
   {
		if(flagServo[i] == 0)
		{
			SetPIN(1, i + 23, ON);			//Servo 1: P1.23 (expansion 3)		y Servo 2: P1.24 (expansion 13)
		}

		if(flagServo[i] >= duty[i])
		{
			SetPIN(1, i + 23, OFF);
		}

		flagServo[i]++;

		if(flagServo[i] >= 20 * MILISEGUNDOS)
		{
			flagServo[i] = 0;
			duty[i] = proximoDuty[i];
		}
   }
}


void ModificarServo( uint8_t servo, uint16_t dato)
{
	proximoDuty[servo] = dato / 100;		//1500 us = 15 decimas de ms

}


void InicializarServos(void)
{
	for(int i = 0; i < 2; i++)
	{
		SetPINSEL( 1 , 23 + i , 00 );
		SetPINMODE( 1 , 23 + i , 2);
		SetDIR( 1 , 23 + i , 1 );
		SetPIN(1, 23 + i, OFF);
	}
}

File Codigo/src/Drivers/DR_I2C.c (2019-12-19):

/**
  \file i2c.c
  \brief Se encuentran las rutinas de manejo de I2C a nivel de drivers.
  \author Grupo 8 - R2003
  \date 2019.10.19
  \version 1.2
*/


#include "all.h"



/**
  \var volatile uint8_t txBufferI2C[I2C_TX_BUFF_SIZE];
  \brief Almacena los datos a enviar por el I2C1.
  \author Grupo 8 - R2003
  \date 2019.11.06
*/
volatile uint8_t txBufferI2C[I2C_TX_BUFF_SIZE];

/**
  \var volatile uint8_t rxBuffI2C[I2C_RX_BUFF_SIZE];
  \brief Almacena los datos a recibidos por el I2C1..
  \author Grupo 8 - R2003
  \date 2019.11.06
*/
volatile uint8_t rxBuffI2C[I2C_RX_BUFF_SIZE];

/**
  \var volatile uint8_t estadoI2C;
  \brief Almacena el estado actual del periférico I2C1.
  \author Grupo 8 - R2003
  \date 2019.11.06
*/
volatile uint8_t estadoI2C;

/**
  \var volatile uint8_t slaveAddr;
  \brief Almacena la dirección de slave I2C a la que se le va a hablar.
  \author Grupo 8 - R2003
  \date 2019.11.06
*/
volatile uint8_t slaveAddr;

/**
  \var volatile uint8_t txBuffI2CSize;
  \brief Almacena el tamaño de datos a enviar por el módulo I2C1.
  \author Grupo 8 - R2003
  \date 2019.11.06
*/
volatile uint8_t txBuffI2CSize;

/**
  \var volatile uint8_t rxBuffI2CSize;
  \brief Almacena el tamaño de datos a recibir por el módulo I2C1.
  \author Grupo 8 - R2003
  \date 2019.11.06
*/
volatile uint8_t rxBuffI2CSize;

/**
  \var volatile uint8_t currentAdress;
  \brief Almacena la última dirección con la que se hablo.
  \author Grupo 8 - R2003
  \date 2019.11.06
*/
volatile uint8_t currentAdress;

/**
  \var volatile uint8_t isDummyWrite;
  \brief Flag para indicar escritura y lectura simultanea del periférico I2C1.
  \author Grupo 8 - R2003
  \date 2019.11.06
*/
volatile uint8_t isDummyWrite;


/**
  \fn void I2C1_IRQHandler(void);
  \brief Handler de la interrupcion para I2C1. Se encarga de generar la comunicación a partir de la información suminstrada por el registro I2C1STAT.
  \author Grupo 8 - R2003
  \date 2019.11.6
*/
//-----------------------------------------------------
void I2C1_IRQHandler(void)
{
	static uint8_t dataCount = 0;	// Contador Incremental del estado del envío
	uint8_t estado;					// El estado es uint8_t y se modifica cada vez que se interrumpe mediante este handler

	estado = I2C1STAT & 0xFF;		// El estado solmanete esta representado x los primeros 8bit de I2C1STAT

	switch(estado)
	{
		case 0x08:				     				// A START condition has been transmitted.
			I2C1DAT = slaveAddr;  					// Cargo SLA+W/R
			I2C1CONCLR = (1 << STA) | (1 << SI);	// Apago STA, Limpio el flag de interrupcion.
			break;

		case 0x10:					  				// A repeated START condition has been transmitted.
			I2C1DAT = slaveAddr;   					// Cargo SLA+W/R
			I2C1CONCLR = (1 << STA) | (1 << SI);	// Apago STA, Limpio el flag de interrupcion.
			break;

			//TRASMITTER MODE--------------------------------------------------------------------------------//
		case 0x18:						   			// SLA+W has been transmitted; ACK has been received.
			I2C1DAT = txBufferI2C[dataCount]; 			// Cargo primer dato.	(dataCount = 0)
			I2C1CONCLR = (1 << STA) | (1 << SI);	// Apago STA, Limpio el flag de interrupcion.
			break;

		case 0x20:		             				// SLA+W has been transmitted; NOT ACK has been received.
			I2C1CONCLR = (1 << STA) | (1 << SI);	// Apago STA, Limpio el flag de interrupcion.
			I2C1CONSET = (1 << I2EN)| (1 << STO);	// Seteo STO para arrancar proceso de STOP.
			estadoI2C = I2C_FAILED;  				// Informo de falla de transmision.
			dataCount = 0;
			break;

		case 0x28:									// Data byte in I2DAT has been transmitted; ACK has been received.
			dataCount++;		   					// Incremento el contador del buffer.
			if(dataCount >= txBuffI2CSize)				// Pregunto si es el último dato.
			{
				I2C1CONCLR = (1 << STA) | (1 << SI);		// Apago STA, Limpio el flag de interrupcion.
				I2C1CONSET = (1 << (4 + isDummyWrite));  	// Seteo STO para proceso de STOP o STA para otra condicion de START.
				if(isDummyWrite)
				{
					slaveAddr |= 0x01;						// Retransmito en modo READ
				}else{
					estadoI2C = I2C_IDLE;					// Entro en modo oscioso
				}
				dataCount = 0;								// De cualquier modo reseteo el buffer
			}else{
				I2C1DAT = txBufferI2C[dataCount];	 			// Cargo dato.
				I2C1CONCLR = (1 << STA) | (1 << SI);		// Apago STA, Limpio el flag de interrupcion.
			}
			break;

		case 0x30:					  				// Data byte in I2DAT has been transmitted; NOT ACK has been received.
			I2C1CONCLR = (1 << STA) | (1 << SI);	// Apago STA, Limpio el flag de interrupcion.
			I2C1CONSET = (1 << I2EN)| (1 << STO);	// Seteo STO para arrancar proceso de STOP.
			estadoI2C = I2C_IDLE;	   				// Libero al periférico para nueva transmisión.
			dataCount = 0;
			break;

		case 0x38:									// Arbitration lost in SLA+R/W or Data bytes.
			I2C1CONCLR = (1 << STA) | (1 << SI);	// Apago STA, Limpio el flag de interrupcion.
			dataCount = 0;
			break;

			//RECEIVER MODE---------------------------------------------------------------------------------//
		case 0x40:									// SLA+R has been transmitted; ACK has been received.
			I2C1CONCLR = (1 << STA) | (1 << SI);	// Apago STA, Limpio el flag de interrupcion.
			I2C1CONSET = (1 << AA);					// Pongo el bit de ACK
			break;

		case 0x48:									// SLA+R has been transmitted; NOT ACK has been received.
			I2C1CONCLR = (1 << STA) | (1 << SI);	// Apago STA, Limpio el flag de interrupcion.
			I2C1CONSET = (1 << STO);				// Pongo el bit de STOP
			estadoI2C = I2C_FAILED; 				// Falló
			dataCount = 0;
			break;

		case 0x50:									// Data byte has been received; ACK has been returned.
			rxBuffI2C[dataCount] = I2C1DAT;			// Guardo en el buffer el dato recibido
			dataCount++;
			if(dataCount >= rxBuffI2CSize -1)			// Si se llenó el buffer
			{
				I2C1CONCLR = (1 << STA) | (1 << SI) | (1 << AA);	// APAGO START - LIMPIO FLAG - APAGO ACK
			}else{
				I2C1CONCLR = (1 << STA) | (1 << SI);				// Apago START - LIMPIO FLAG
				I2C1CONSET =  (1 << AA);							// Pongo el bit de ACK
			}
			break;

		case 0x58:									// Data byte has been received; NOT ACK has been returned.
			rxBuffI2C[dataCount] = I2C1DAT;			// Recibo dato
			I2C1CONCLR = (1 << STA) | (1 << SI);	// Apago STA, Limpio el flag de interrupcion.
			I2C1CONSET =  (1 << STO);				// Pongo el bit de STOP
			estadoI2C = I2C_DATAV;					// Especifico que hay Data Available para I2C1_data_read
			dataCount = 0;
			break;

		default:
			I2C1CONCLR = (1 << STA) | (1 << SI);	// Apago STA, Limpio el flag de interrupcion.
			break;
	}
}
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

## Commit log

2019-07-22 v1.1
    Básicamente organice todo lo que me parecio. Hice alguna maquina y poco mas.
2019-07-22 v1.1
    Cambie de lugar un par de cosas, nada muy significativo.
2019-07-23 Agregue Doxygen
    No estaría funcionando :angry:
    Hay que preguntar que le pasa :(
2019-07-23 Agregue mas recursos
    Meto las carpetas de documentación y de las piezas 3D.
    [Cronograma_v4.0.xlsx, Ensamblaje.SLDASM, Freno.SLDPRT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]
2019-07-23 Version 1.2
    Agregue creo que toda la maquina de control y la de ejecutar. Falta ponerle la parte para visualizar por el display el valor de Actual.
    Fijense si les parece bien, porque modifique la lógica en algunos puntos que creo que estaban mal.
2019-07-24 Modificacion de las piezas
    Agregue un modelo 3D del giroscopo en el ensamblaje y modifique la pieza para que se adapte bien.
    [Ensamblaje.SLDASM, GY-91.SLDPRT, Gopro Hero 4.SLDPRT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]
2019-08-01 Actualización Pieza
    Solamente modifique las piezas (el dia que imprimimos la primera) y toque dos pavadas en el code
    [Ensamblaje.SLDASM, GY-91.step, Pieza 1.SLDPRT]
2019-08-01 Actualice los archivos de documentacion
2019-08-06 Versión 2.0
    Versión entregable para el día 7/08
    [Cronograma_v4.0.xlsx, Ensamblaje.SLDASM, Freno.SLDPRT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]
2019-08-06 V2.0 - "Bien" organizada
    [Cronograma_v4.0.xlsx, Ensamblaje.SLDASM, Freno.SLDPRT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]
2019-08-07 UPDATE IMPORTANTE
    En este commit se modifica la estructura de los archivos adentro de la carpeta "Codigo". Se agrega un "Instrucciones.txt" donde se explica como hacer para programar en el mcu.
2019-08-30 Implementación del servo epicardo
    Che gente, por si no sabian... Repe es de River!!!
2019-09-07 Subo las cosas de GUI
2019-09-10 Agrego carpeta I2C
    Subo codigo y los screenshots de la descripcion de los pines
2019-09-10 QT_Mateo-Repe
    Les subo lo que hicimos con mateo y repe el lunes.
2019-09-11 Interfaz Grafica
    Paso lo de Qt. Borre las carpetas que decian Comunicacion_Repe o Interfaz_Matero.. si las quieren pueden ir al historial y bajarse esas versiones. Lo unico no borren todos los avances a la mierda pq 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
2019-09-11 Borro cosas de QT para hacer merge
2019-09-11 Ejemplo I2C LPCOPEN 1769
2019-09-11 Cambio Interfaz en clase
    Primeros cambios de la interfaz, para trbajar y que se guarde lo anterior, por las dudas
2019-09-12 Nueva version MCU
    Básicamente, lo unico que hice fue re-organizar las carpetas. Aparte cambie de lugar algunas rutinas para que esten en los sectores de "primitivas" "drivers" o "app" segun corresponda. Documente algu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
2019-09-16 INTERFAZ CASI ANDANDO, NO LEE
    No lee porque me parece que tiene un problema la señal que se emite cuando hay datos en el puerto
2019-09-17 i2c_fedex
    codigo de fede ajustado a lo que necesitamos
    [ctestcases.cfg, lpc1769.cfg, lpc4337.cfg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]
2019-09-18 INTERFAZ COMPLETAMENTE FUNCIONAL
    La estuvimos viendo con Lisandro, y ahora anda para versiones de Qt que no sean la poronga de la 5.13.1
2019-10-13 Hasta Acá la GUI funciona
2019-10-14 Organizo carpetas
    [ctestcases.cfg, lpc1769.cfg, lpc4337.cfg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]
2019-10-14 Se Actualiza el proyecto de MCU
    Lo único que cambia es que el proyecto que este sea el actualizado
2019-10-16 Mejora Comunicación Serie.
    Hay un error: solamente recibe 1 de cada 2 envíos.. Ver TODO en el codigo de maquinaComSerie.c
    [maquinaComSerie.c, maquinaEjecutando.c, maquinaGeneral.c]
2019-10-23 Mejora Qt
    Se mejora el procedimiento para el envío mediante comunicación Serie
2019-10-23 MCU - Agregado Comunicación Serie
    Se agrega procedimiento compatible con interrupciones para la comunicación Serie
2019-10-23 First Commit
    Se agrega un módulo aparte en la carpeta de I2C. Esto incluye un driver de I2C para LPC1769 y algunas funcionalidades del MPU9250. (NO ESTA TESTEADO)
2019-10-30 Driver I2C funcionando
2019-10-31 AnalizarTrama() + Graficar angulos!
    Qt ahora sabe analizar tramas con PIT ROL YAW y encima grafica los angulos... TODO: Agregar en la rutina de recibir que actualice los angulos que pertenecen al formulario de Plotting
2019-11-06 Cambio dos boludeces en la GUI
2019-11-06 I2C FUNCIONANDO 100/100
    [ctestcases.cfg, lpc1769.cfg, lpc4337.cfg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]
2019-11-09 Agrego envio de datos en MCU
2019-12-01 First Try Dr Servos via Systick
2019-12-02 New version of ServoDriver
2019-12-02 move drservo to drivers folder
2019-12-04 Todo en c++ (Agregue lo que cambio Alejo tmb)
2019-12-05 Mejoras en el funcionamiento de QT
2019-12-05 Agrego las piezas 3D nuevas :smile:
    [Emax ES08A.SLDPRT, Ensamblaje.SLDASM, Freno.SLDPRT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]
2019-12-08 Agrego sistema de control y filtro de angulos
2019-12-11 Se agrega plotting funcional de angulos con algunos filtros
2019-12-15 New Final Folder
    Ojo que hay q terminar de completar el informe
2019-12-19 Last Commit
    Dale BOOOOOCA :beers:
    [1era pieza.STL, 2da pieza.STL, 3era pieza.STL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]
